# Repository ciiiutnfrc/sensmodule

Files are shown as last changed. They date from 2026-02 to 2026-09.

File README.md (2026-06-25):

# Módulo sensor de código abierto para robot móvil

El módulo de sensores consta de dos componentes principales:
1. un anillo de sensores de ultrasonido o sonar (Sonar NAvigation and Ranging) para medición de distancia
1. una unidad de medición inercial, que integra un acelerómetro y un giroscopio (IMU, Inertial Measurement Unit)

Para sujetar y distribuir los transductores de ultrasonido como anillo circular se diseñó un soporte mecánico especı́fico. Todo el conjunto se aloja en un gabinete dedicado fabricado con impresión 3D. El diseño electrónico fue realizado utilizando [KiCAD](https://www.kicad.org/), mientras que para el diseño mecánico del soporte de los transductores y el gabinete se utilizó [FreeCAD](https://www.freecad.org/); ambos decódigo abierto.

Está implementado en base a la placa de desarrollo ["Raspberry Pi Pico"](https://www.raspberrypi.com/documentation/microcontrollers/pico-series.html#pico1), cuyo firmware actúa como nodo de [ROS](https://www.ros.org/) utilizando el framework [micro-ROS](https://micro.vulcanexus.org/). Este nodo es responsable de adquirir los datos de todos los sensores y publicarlos en los topics correspondientes para su procesamiento en la computadora principal del robot.

## Videos
* [ModSens - sensores de distancia por ultrasonido](https://www.youtube.com/watch?v=mX4Z-RGdCro)
* [ModSens - visualización RViz sobre el robot RoMAA-II](https://www.youtube.com/watch?v=sf0R5RFJkfc)
* [ModSens - sensores inerciales](https://www.youtube.com/watch?v=RdyZEUkLeZU)

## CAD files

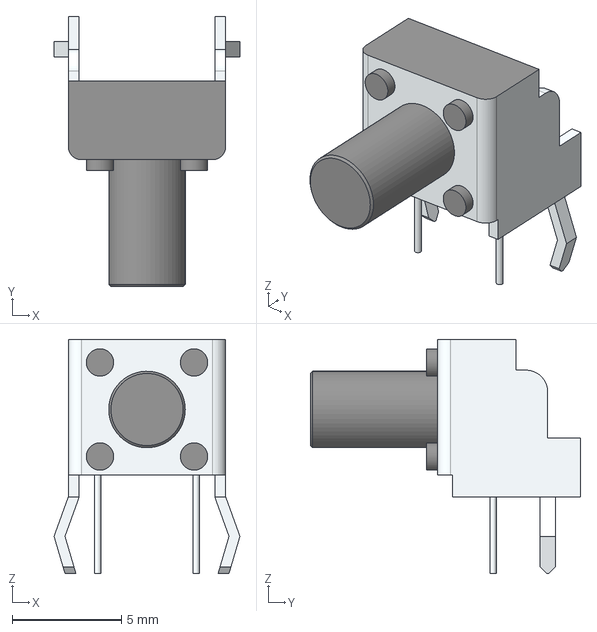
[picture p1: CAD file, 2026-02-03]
hardware/3DModels/SW-DTSA-65K-V.stp
8.50 x 12.3 x 10.7 mm

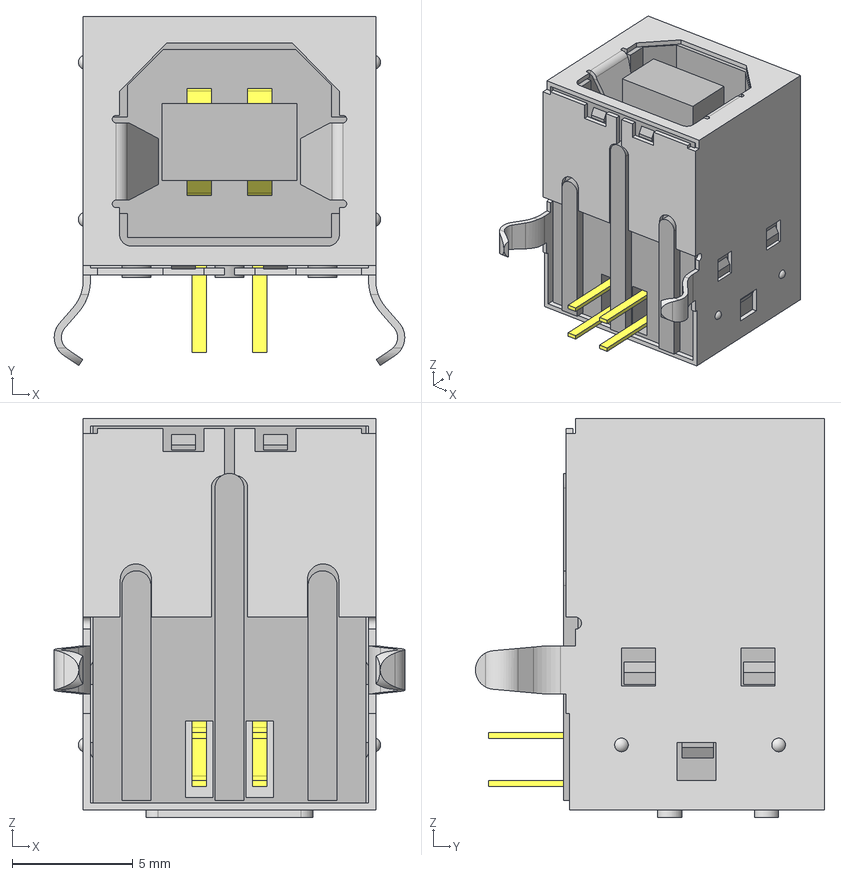
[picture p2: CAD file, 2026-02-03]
hardware/3DModels/USB-B-S-F-B-TH.stp
14.5 x 14.4 x 16.5 mm
USB-B-S-TH_S
USB-B-S-B-TH_B
USB-B-S-TH_P

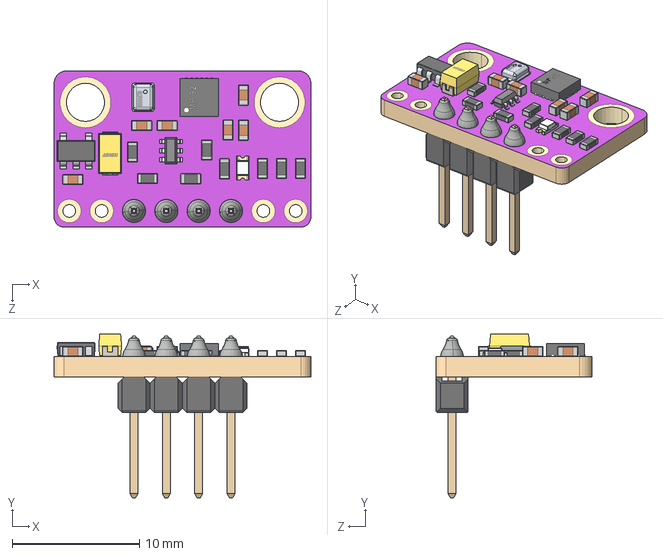
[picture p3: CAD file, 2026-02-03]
hardware/3DModels/IMU.STEP
20.2 x 12.9 x 12.3 mm

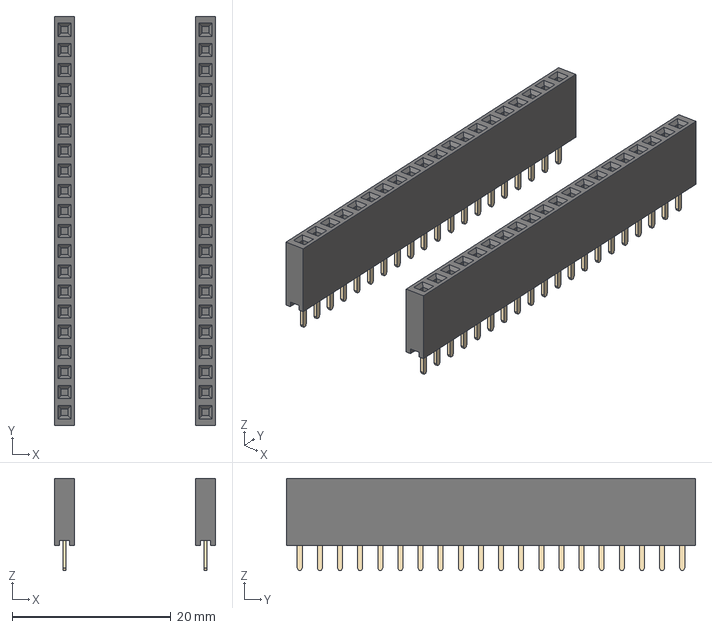
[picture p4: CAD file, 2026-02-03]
hardware/3DModels/DIP-40_W17.78mm_Socket.step
20.3 x 51.6 x 11.6 mm
SIP-20_Socket x 2

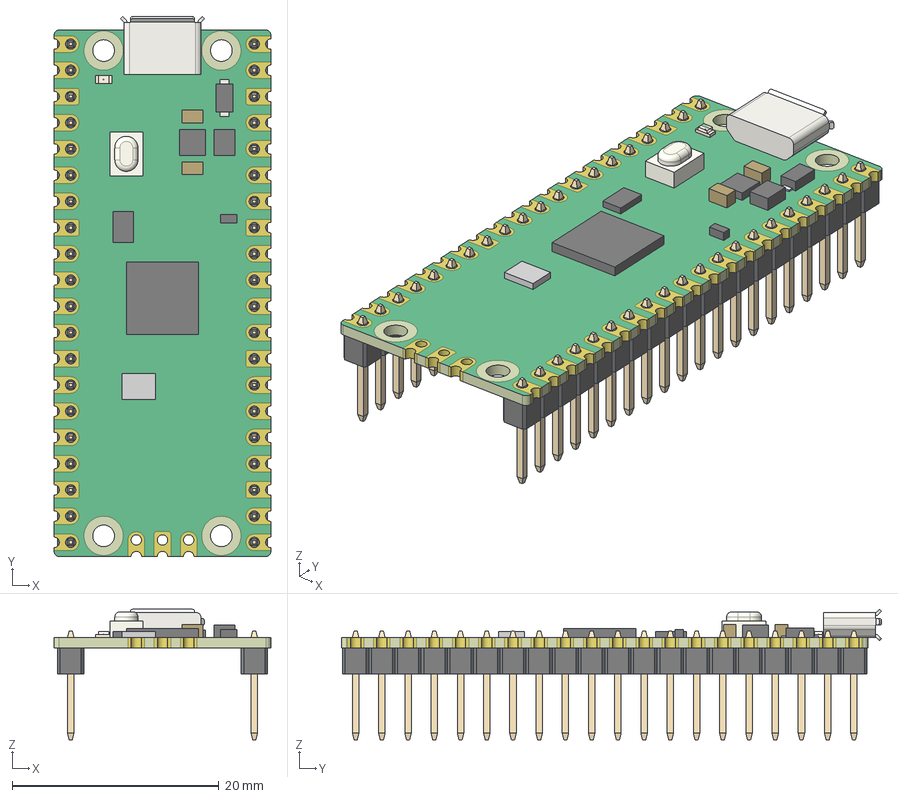
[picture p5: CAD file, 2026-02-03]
hardware/3DModels/RaspberryPi_Pico_AddedHeaders_Socketed.step
21.0 x 52.3 x 12.6 mm
Pico_Board
C1_47u
C2_47u
D1_MBR120VLSFT1G
D2_QSME-C194_Base
D2_QSME-C194_Phosphor
D2_QSME-C194_Lens
J1_690T505-x62-01x
L1_2u2
Q1_DMG1012T
SW1_TP-1221U-K9K5325
U1_RP2040
U2_RT6150B-33GQW
U3_W25Q16JVUXIQ
X1_X12M000000S096
SIP-20_Header x 2

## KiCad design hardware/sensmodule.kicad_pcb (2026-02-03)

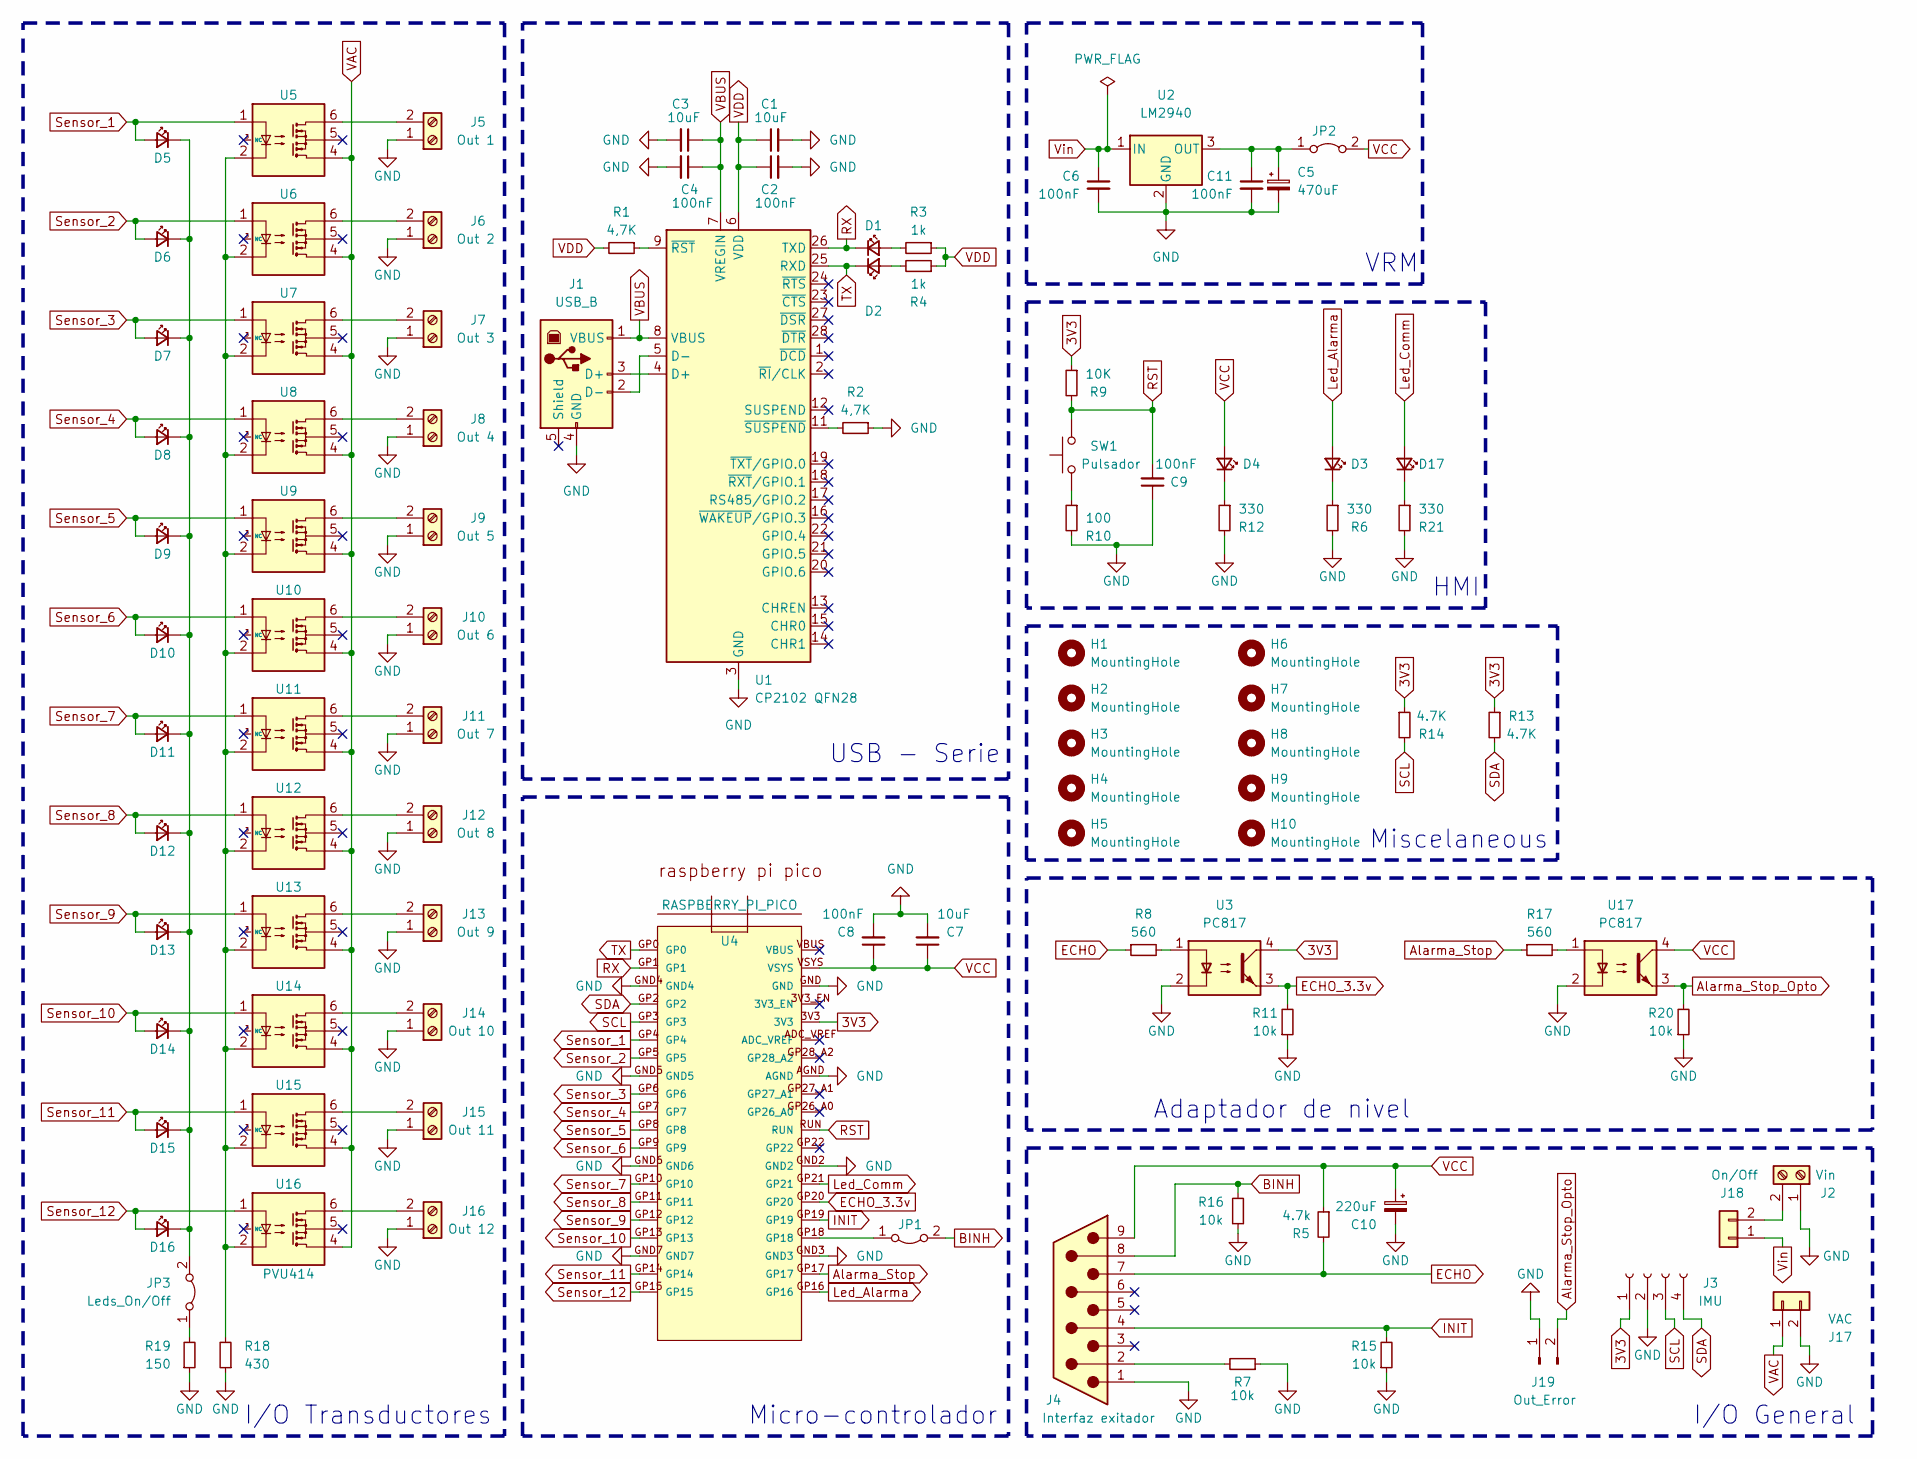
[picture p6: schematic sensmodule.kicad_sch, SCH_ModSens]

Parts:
C1, C3, C7: 10uF; C_0805_2012Metric_Pad1.18x1.45mm_HandSolder
C2, C4, C6, C8, C9, C11: 100nF; C_0805_2012Metric_Pad1.18x1.45mm_HandSolder
C5: 470uF; CP_Radial_D6.3mm_P2.50mm
C10: 220uF; CP_Radial_D5.0mm_P2.00mm
D1: TX LED Verde; LED_D3.0mm_Clear
D2: RX LED Azul; LED_D3.0mm_Clear
D3, D17: LED Verde 3mm; PinHeader_1x02_P2.54mm_Vertical
D4: LED Amarillo 3mm; PinHeader_1x02_P2.54mm_Vertical
D5, D6, D7, D8, D9, D10, D11, D12, D13, D14, D15, D16: LED Rojo 3mm; LED_D3.0mm_Clear
H1, H2, H3, H4, H5, H6, H7, H8, H9, H10: MountingHole; MountingHole_3.2mm_M3
J1: USB_B; USB_B_OST_USB-B1HSxx_Horizontal
J2: Vin; PhoenixContact_MC_1,5_2-G-5.08_1x02_P5.08mm_Horizontal
J3: IMU; PinSocket_1x04_P2.54mm_Vertical
J4: Interfaz exitador; Molex_Picoflex_90325-0010_2x05_P1.27mm_Vertical
J5: Out 1; PhoenixContact_MC_1,5_2-G-5.08_1x02_P5.08mm_Horizontal
J6: Out 2; PhoenixContact_MC_1,5_2-G-5.08_1x02_P5.08mm_Horizontal
J7: Out 3; PhoenixContact_MC_1,5_2-G-5.08_1x02_P5.08mm_Horizontal
J8: Out 4; PhoenixContact_MC_1,5_2-G-5.08_1x02_P5.08mm_Horizontal
J9: Out 5; PhoenixContact_MC_1,5_2-G-5.08_1x02_P5.08mm_Horizontal
J10: Out 6; PhoenixContact_MC_1,5_2-G-5.08_1x02_P5.08mm_Horizontal
J11: Out 7; PhoenixContact_MC_1,5_2-G-5.08_1x02_P5.08mm_Horizontal
J12: Out 8; PhoenixContact_MC_1,5_2-G-5.08_1x02_P5.08mm_Horizontal
J13: Out 9; PhoenixContact_MC_1,5_2-G-5.08_1x02_P5.08mm_Horizontal
J14: Out 10; PhoenixContact_MC_1,5_2-G-5.08_1x02_P5.08mm_Horizontal
J15: Out 11; PhoenixContact_MC_1,5_2-G-5.08_1x02_P5.08mm_Horizontal
J16: Out 12; PhoenixContact_MC_1,5_2-G-5.08_1x02_P5.08mm_Horizontal
J17: VAC; Molex_KK-254_AE-6410-02A_1x02_P2.54mm_Vertical
J18: On/Off; Molex_KK-254_AE-6410-02A_1x02_P2.54mm_Vertical
J19: Out_Error; PinHeader_1x02_P2.54mm_Vertical
JP1: BINH_On/Off; SolderJumper-2_P1.3mm_Open_Pad1.0x1.5mm
JP2: Main_On/Off; SolderJumper-2_P1.3mm_Open_Pad1.0x1.5mm
JP3: Leds_On/Off; PinHeader_1x02_P2.54mm_Vertical
R1, R2: 4,7K; R_0805_2012Metric_Pad1.20x1.40mm_HandSolder
R3, R4: 1k; R_0805_2012Metric_Pad1.20x1.40mm_HandSolder
R5: 4.7k; R_0805_2012Metric_Pad1.20x1.40mm_HandSolder
R6, R12, R21: 330; R_0805_2012Metric_Pad1.20x1.40mm_HandSolder
R7, R11, R15, R16, R20: 10k; R_0805_2012Metric_Pad1.20x1.40mm_HandSolder
R8, R17: 560; R_0805_2012Metric_Pad1.20x1.40mm_HandSolder
R9: 10K; R_0805_2012Metric_Pad1.20x1.40mm_HandSolder
R10: 100; R_0805_2012Metric_Pad1.20x1.40mm_HandSolder
R13, R14: 4.7K; R_0805_2012Metric_Pad1.20x1.40mm_HandSolder
R18: 430; R_0805_2012Metric_Pad1.20x1.40mm_HandSolder
R19: 150; R_0805_2012Metric_Pad1.20x1.40mm_HandSolder
SW1: Pulsador; SW_SPST_Omron_B3F-315x_Angled
U1: CP2102 QFN28; QFN-28-1EP_5x5mm_P0.5mm_EP3.35x3.35mm
U2: LM2940; TO-220-3_Horizontal_TabDown
U3, U17: PC817; DIP-4_W7.62mm_Socket_LongPads
U4: RASPBERRY_PI_PICO
U5, U6, U7, U8, U9, U10, U11, U12, U13, U14, U15, U16: PVU414; DIP-6_W7.62mm_Socket_LongPads

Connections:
3V3: J3.1, R9.1, R13.1, R14.1, U3.4, U4.3V3
Alarma_Stop: R17.1, U4.GP17
Alarma_Stop_Opto: J19.2, R20.2, U17.3
BINH: J4.8, JP1.2 (B), R16.2
ECHO: J4.7, R5.2, R8.1
ECHO_3.3v: R11.2, U3.3, U4.GP20
GND: C1.2, C2.2, C3.2, C4.2, C5.2, C6.2, C7.2, C8.2, C9.1, C10.2, C11.2, J1.4 (GND), J2.1, J3.2, J4.1, J5.1, J6.1, J7.1, J8.1, J9.1, J10.1, J11.1, J12.1, J13.1, J14.1, J15.1, J16.1, J17.2, J19.1, R2.1, R6.2, R7.1, R10.2, R11.1, R12.2, R15.1, R16.1, R18.1, R19.1, R20.1, R21.2, U1.3 (GND), U1.29 (GND), U2.2 (GND), U3.2, U4.AGND, U4.GND, U4.GND2, U4.GND3, U4.GND4, U4.GND5, U4.GND6, U4.GND7, U17.2
INIT: J4.4, R15.2, U4.GP19
Led_Alarma: D3.2 (A), U4.GP16
Led_Comm: D17.2 (A), U4.GP21
unnamed: D1.2 (A), R3.2
unnamed: D2.2 (A), R4.2
unnamed: D3.1 (K), R6.1
unnamed: D4.1 (K), R12.1
unnamed: D5.1 (K), D6.1 (K), D7.1 (K), D8.1 (K), D9.1 (K), D10.1 (K), D11.1 (K), D12.1 (K), D13.1 (K), D14.1 (K), D15.1 (K), D16.1 (K), JP3.2 (B)
unnamed: D17.1 (K), R21.1
unnamed: J1.3 (D+), U1.4 (D+)
unnamed: J1.2 (D-), U1.5 (D-)
unnamed: J4.2, R7.2
unnamed: J5.2, U5.6
unnamed: J6.2, U6.6
unnamed: J7.2, U7.6
unnamed: J8.2, U8.6
unnamed: J9.2, U9.6
unnamed: J10.2, U10.6
unnamed: J11.2, U11.6
unnamed: J12.2, U12.6
unnamed: J13.2, U13.6
unnamed: J14.2, U14.6
unnamed: J15.2, U15.6
unnamed: J16.2, U16.6
unnamed: J2.2, J18.2
unnamed: JP1.1 (A), U4.GP18
unnamed: C5.1, C11.1, JP2.1 (A), U2.3 (OUT)
unnamed: JP3.1 (A), R19.2
unnamed: R8.2, U3.1
unnamed: R10.1, SW1.1
unnamed: R17.2, U17.1
unnamed: R18.2, U5.2, U6.2, U7.2, U8.2, U9.2, U10.2, U11.2, U12.2, U13.2, U14.2, U15.2, U16.2
unnamed: R1.1, U1.9 (~RST)
unnamed: R2.2, U1.11 (~SUSPEND)
RST: C9.2, R9.2, SW1.2, U4.RUN
RX: D1.1 (K), U1.26 (TXD), U4.GP1
SCL: J3.3, R14.2, U4.GP3
SDA: J3.4, R13.2, U4.GP2
Sensor_1: D5.2 (A), U4.GP4, U5.1
Sensor_2: D6.2 (A), U4.GP5, U6.1
Sensor_3: D7.2 (A), U4.GP6, U7.1
Sensor_4: D8.2 (A), U4.GP7, U8.1
Sensor_5: D9.2 (A), U4.GP8, U9.1
Sensor_6: D10.2 (A), U4.GP9, U10.1
Sensor_7: D11.2 (A), U4.GP10, U11.1
Sensor_8: D12.2 (A), U4.GP11, U12.1
Sensor_9: D13.2 (A), U4.GP12, U13.1
Sensor_10: D14.2 (A), U4.GP13, U14.1
Sensor_11: D15.2 (A), U4.GP14, U15.1
Sensor_12: D16.2 (A), U4.GP15, U16.1
TX: D2.1 (K), U1.25 (RXD), U4.GP0
VAC: J17.1, U5.4, U6.4, U7.4, U8.4, U9.4, U10.4, U11.4, U12.4, U13.4, U14.4, U15.4, U16.4
VBUS: C3.1, C4.1, J1.1 (VBUS), U1.7 (VREGIN), U1.8 (VBUS)
VCC: C7.1, C8.1, C10.1, D4.2 (A), J4.9, JP2.2 (B), R5.1, U4.VSYS, U17.4
VDD: C1.1, C2.1, R1.2, R3.1, R4.1, U1.6 (VDD)
Vin: C6.1, J18.1, U2.1 (IN)

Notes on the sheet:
Adaptador de nivel
VRM
Micro-controlador
I/O General
Miscelaneous
I/O Transductores
USB - Serie
HMI

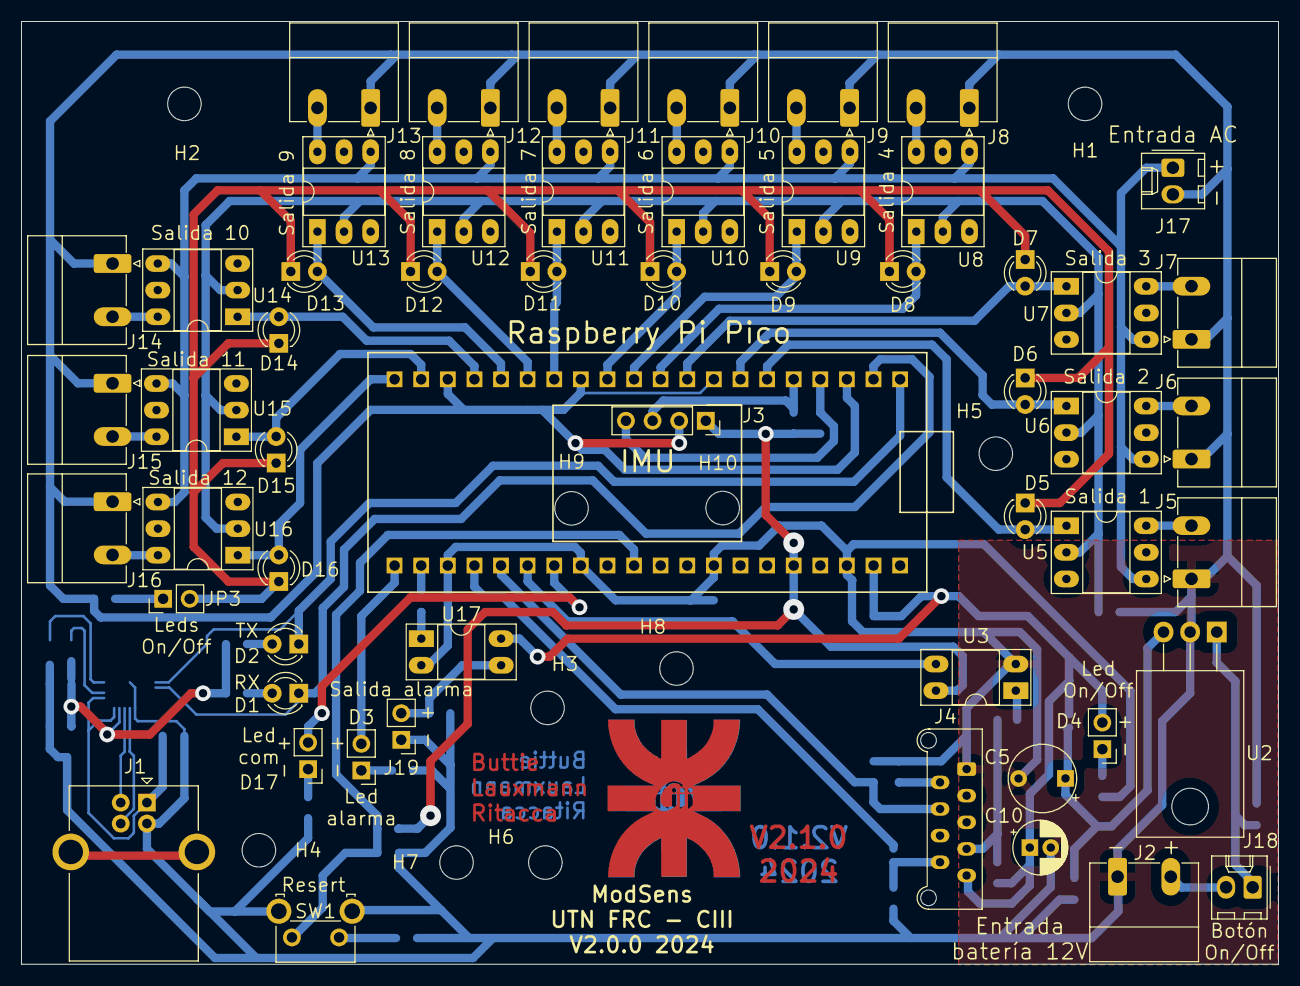
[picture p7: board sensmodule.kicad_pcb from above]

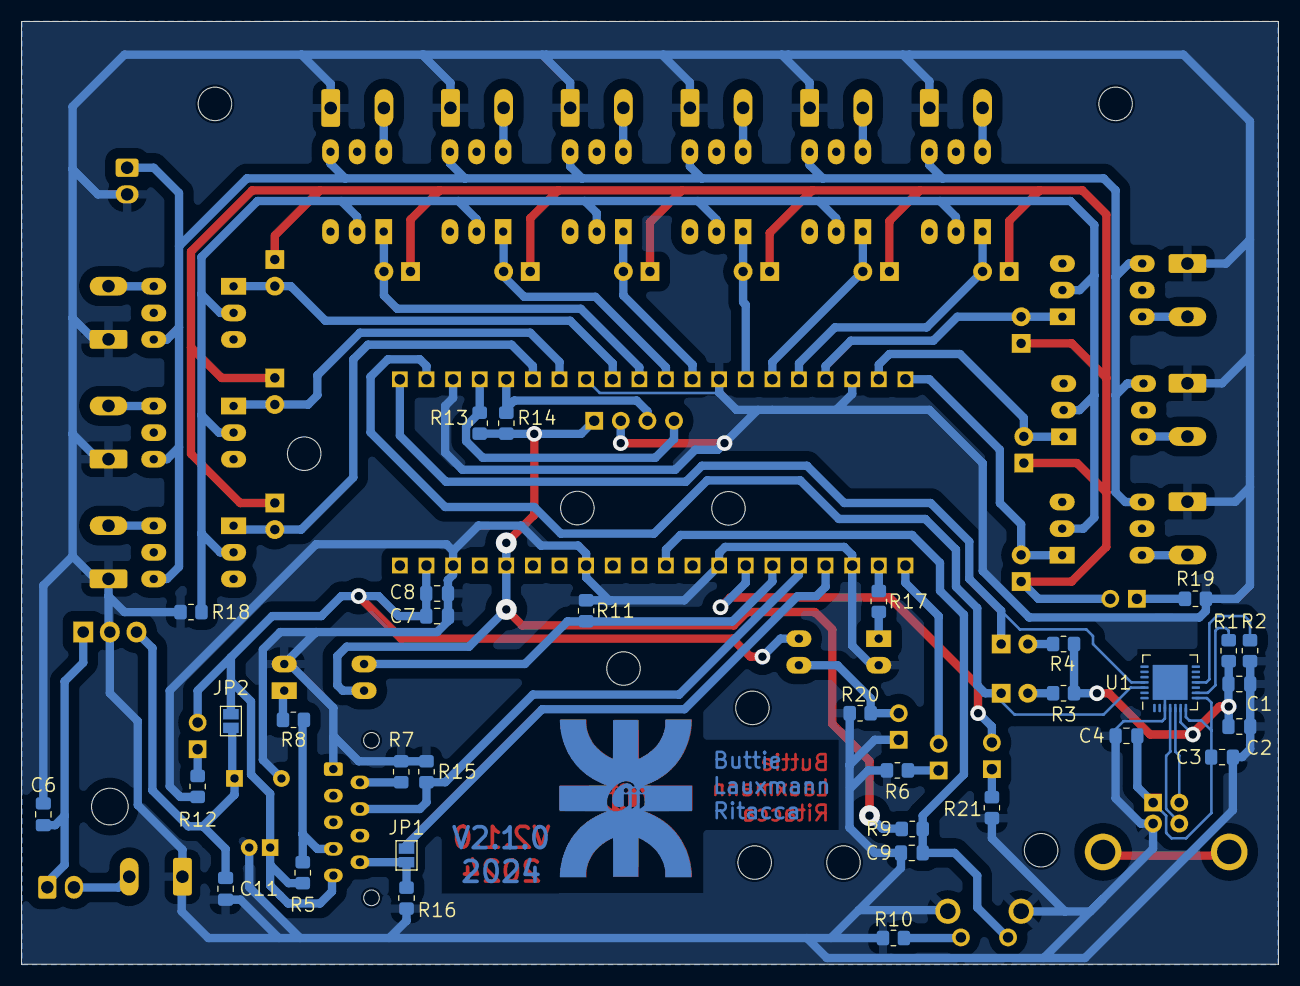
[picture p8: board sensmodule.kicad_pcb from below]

Board: 2 copper layers, 120.0 x 90.0 mm, 99 parts (33 on the bottom side), 63 nets.

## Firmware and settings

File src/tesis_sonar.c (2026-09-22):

/////////////////////////////////////////////////////
//LIBRERIAS

//Librerias STD
#include <stdio.h>
#include <unistd.h>
#include <math.h>

//Librerias propias de MicroRos
#include <rcl/rcl.h>
#include <rcl/error_handling.h>
#include <rclc/rclc.h>
#include <rclc/executor.h>
#include <std_msgs/msg/int16.h>
#include <std_msgs/msg/float32.h>
#include <rmw_microros/rmw_microros.h>
#include <micro_ros_utilities/type_utilities.h>

//Librerias propias de raspi pico
#include "pico/stdlib.h"
#include "pico_uart_transports.h"
#include "hardware/gpio.h"
#include "hardware/timer.h"

//I2C Para IMU
#include "hardware/i2c.h"
#include "pico/binary_info.h"

//Librerias de mensajes
#include <sensor_msgs/msg/range.h>
#include <sensor_msgs/msg/imu.h>

/////////////////////////////////////////////////////
//CONSTANTES

//Tiempo de INIT
#define TON_INIT 55
#define TOFF_INIT 20

//Numero de sensores por defecto
#define MAX_SENSORES 9

//Distancia maxima y minima por defecto (Mts)
#define MAX_DIST 5 
#define MIN_DIST 0.4 

#define HISTERESIS 0.05 //En mts

#define UMBRAL_SEGURIDAD 0.5

//Lobulo del sensor
#define FIELD_VIEW 0.244346

//Frecuencias de Publicacion (Hz)
#define FREC_SONAR 1
#define FREC_IMU 10

#define FREC_CALLBACK 20

#define MAX_FREC_SONAR 2
#define MAX_FREC_IMU 20

#define MIN_FREC_SONAR 0.5
#define MIN_FREC_IMU 5

//GPIO
#define LED_PIN 21
#define LED_INTEGRADO 25
#define ECHO 20 
#define INIT 19 

#define SEG_1 16
#define SEG_2 17

//UART
#define UART_TX_PIN 0
#define UART_RX_PIN 1
#define UART_USADA uart0
#define BAUD_RATE 921600

//ROS
#define NODE_NAME "mod_sens"
#define NAMESPACE_NAME "modsens"
#define TOPIC_NAME_SONAR "range"
#define TOPIC_NAME_IMU "imu"
#define TOPIC_NAME_CANT_SENSORES "cant_sensores"
#define TOPIC_NAME_DIST_SEG "dist_seguridad"

#define TIMEOUT_MS 1000
#define INTENTOS_CONN 10

//I2C
#define I2C_PORT i2c1
#define SDA_PIN 2
#define SCL_PIN 3
#define FREQ_I2C 100 * 1000

#define LSM6DS3_ADDR 0x6B
#define LSM6DS3_WHO_AM_I  0x0F
#define LSM6DS3_CTRL1_XL  0x10
#define LSM6DS3_CTRL2_G   0x11
#define LSM6DS3_OUTX_L_XL 0x28
#define OUTX_L_G 0x22

#define PIN_OCTO_1 4
#define PIN_OCTO_2 5
#define PIN_OCTO_3 6
#define PIN_OCTO_4 7
#define PIN_OCTO_5 8
#define PIN_OCTO_6 9
#define PIN_OCTO_7 10
#define PIN_OCTO_8 11
#define PIN_OCTO_9 12
#define PIN_OCTO_10 13
#define PIN_OCTO_11 14
#define PIN_OCTO_12 15

/////////////////////////////////////////////////////
//VARIABLES GLOBALES

//Timer
uint64_t start_time = 0, end_time = 0;
double elapsed_time_us = 0;

uint64_t periodo_imu = 0;
uint64_t periodo_sonar = 0;

//Medicion
double medicion = 0;
double CORRECCION_IMU_ACEL = (double)100/(double)170408;
double CORRECCION_IMU_GIRO = (double)4.375/(double)1000 * (double)0.0175;
int16_t accel_data[3];
int16_t giro_data[3];

//Variables nodo
rcl_node_t node;

rcl_publisher_t publisher_sonar;
rcl_publisher_t publisher_imu;

rcl_subscription_t subscriber_cant_sonar;
rcl_subscription_t subscriber_seguridad;

sensor_msgs__msg__Range__Sequence* sonar_msg;
sensor_msgs__msg__Imu imu_msg;

rcl_timer_t timer_publ_sonar;
rcl_timer_t timer_publ_imu;
int64_t periodo;

rclc_support_t support;

rcl_allocator_t allocator;

// Message object to receive publisher data
std_msgs__msg__Int16 msg_sensores;
std_msgs__msg__Float32 msg_seg;

//Multiplexado
int n_sensor_leido = 0;
int lugar_sensor_leido = 0;

bool medicion_nueva = 0;

//Definiciones
bool sensores_activar[12] = {1,1,1,1,1,1,1,1,1,0,0,0};
int cant_sensores = 0;
int frec_imu = FREC_IMU;
int new_frec_imu = FREC_IMU;
int frec_sonar = FREC_SONAR;

//Cuenta para publicacion
int contador_imu = 0;
int contador_sonar = 0;
int contador_frec = 0;

//Sensado distancia minima
double umbral_seguridad = UMBRAL_SEGURIDAD;
int sensor_seguridad = 0;

/////////////////////////////////////////////////////
//FUNCIONES

/*! \brief Inicializar todos los pines de GPIO
 */
void init_pins(){

    //Seteo de pines
    gpio_init(LED_PIN);
    gpio_set_dir(LED_PIN, GPIO_OUT);

    gpio_init(LED_INTEGRADO);
    gpio_set_dir(LED_INTEGRADO, GPIO_OUT);

    gpio_init(ECHO);
    gpio_set_dir(ECHO, GPIO_IN);

    gpio_init(INIT);
    gpio_set_dir(INIT, GPIO_OUT);

    gpio_init(PIN_OCTO_12);
    gpio_set_dir(PIN_OCTO_12, GPIO_OUT);
    gpio_init(PIN_OCTO_11);
    gpio_set_dir(PIN_OCTO_11, GPIO_OUT);
    gpio_init(PIN_OCTO_10);
    gpio_set_dir(PIN_OCTO_10, GPIO_OUT);
    gpio_init(PIN_OCTO_9);
    gpio_set_dir(PIN_OCTO_9, GPIO_OUT);
    gpio_init(PIN_OCTO_8);
    gpio_set_dir(PIN_OCTO_8, GPIO_OUT);
    gpio_init(PIN_OCTO_7);
    gpio_set_dir(PIN_OCTO_7, GPIO_OUT);
    gpio_init(PIN_OCTO_6);
    gpio_set_dir(PIN_OCTO_6, GPIO_OUT);
    gpio_init(PIN_OCTO_5);
    gpio_set_dir(PIN_OCTO_5, GPIO_OUT);
    gpio_init(PIN_OCTO_4);
    gpio_set_dir(PIN_OCTO_4, GPIO_OUT);
    gpio_init(PIN_OCTO_3);
    gpio_set_dir(PIN_OCTO_3, GPIO_OUT);
    gpio_init(PIN_OCTO_2);
    gpio_set_dir(PIN_OCTO_2, GPIO_OUT);
    gpio_init(PIN_OCTO_1);
    gpio_set_dir(PIN_OCTO_1, GPIO_OUT);

    gpio_init(SEG_1);
    gpio_set_dir(SEG_1, GPIO_OUT);
    gpio_init(SEG_2);
    gpio_set_dir(SEG_2, GPIO_OUT);
}

/*! \brief setear UART para la comunicacion serial de ROS
 */
void init_uart(){

    rmw_uros_set_custom_transport(
        true,
        NULL,
        pico_serial_transport_open,
        pico_serial_transport_close,
        pico_serial_transport_write,
        pico_serial_transport_read
    );

    //uart_init(UART_USADA, BAUD_RATE);
    //gpio_set_function(UART_TX_PIN, GPIO_FUNC_UART);    
    //gpio_set_function(UART_RX_PIN, GPIO_FUNC_UART);
}

/*! \brief Inicializar I2C para la comunicacion con la IMU
 */
void init_i2c(){

    //INICIALIZAR I2C 
    i2c_init(I2C_PORT, FREQ_I2C);

    //Setear pines SDA SCL
    gpio_set_function(SDA_PIN, GPIO_FUNC_I2C);
    gpio_set_function(SCL_PIN, GPIO_FUNC_I2C);

}


/*! \brief Inicializar arreglo de msg de sonar (sensor_msgs__msg__Range)
 */
void init_sonar(){

    sonar_msg = sensor_msgs__msg__Range__Sequence__create(MAX_SENSORES);
    sensor_msgs__msg__Range__Sequence__init(sonar_msg,MAX_SENSORES);

    //Definir que cantidad de sensores estaran activos en un principio
    int nueva_cantidad;

    for(int i = 0; i < MAX_SENSORES; i++){

        if(sensores_activar[i]){

            nueva_cantidad = nueva_cantidad+1;

        }
        
    }

    cant_sensores = nueva_cantidad;

    char frame_id[20];
    for (int i = 1; i <= MAX_SENSORES; i++) {

        // Construir el nombre del sensor con el número correspondiente
        snprintf(frame_id, sizeof(frame_id), "sensor_%d", i);

        // Asignar el nombre construido a la estructura
        strcpy(sonar_msg->data[i-1].header.frame_id.data, frame_id);
        sonar_msg->data[i-1].header.frame_id.size = strlen(sonar_msg->data[i-1].header.frame_id.data);

        sonar_msg->data[i-1].field_of_view = FIELD_VIEW;

        sonar_msg->data[i-1].radiation_type = 0;

        sonar_msg->data[i-1].max_range = MAX_DIST;

        sonar_msg->data[i-1].min_range = MIN_DIST;

    }

}


/*! \brief Inicializar mensaje IMU (sensor_msgs__msg__Imu)
 */
void init_imu(){

    memset(&imu_msg, 0, sizeof(sensor_msgs__msg__Imu));
    sensor_msgs__msg__Imu__init(&imu_msg);

    strcpy(imu_msg.header.frame_id.data, "IMU LSM6DS3");

}


/*! \brief Funcion llamada al reasignar cantidad de sensores
 * 
 * \param msgin mensaje entrante
 */
void subscription_callback_sensores(const void * msgin)
{

    // Cast received message to used type
    const std_msgs__msg__Int16 * msg_sonar = (const std_msgs__msg__Int16 *)msgin;

    // Variable to hold the processed value
    uint16_t recibido = (uint16_t) msg_sonar->data;  // Cast and get value directly
    int nueva_cantidad = 0;

    // Crear el arreglo bool (suponiendo que sensores_activar ya está definido en otro lugar)
    for (int i = 0; i < MAX_SENSORES; i++) {

        // Extraer el bit correspondiente y almacenar en el arreglo
        sensores_activar[i] = (recibido & (1 << i)) != 0;

    }

    for(int i = 0; i < MAX_SENSORES; i++){

        if(sensores_activar[i]){

            nueva_cantidad++;

        }
        
    }

    cant_sensores = nueva_cantidad;
    
    n_sensor_leido = 0;
    lugar_sensor_leido = 0;

    actualizar_periodo_sonar();

    gpio_put(SEG_1,0);
    gpio_put(SEG_2,0);

}


/*! \brief Funcion llamada para reasignar el periodo del sonar al cambiar la cantidad de sensores activos
 */
void actualizar_periodo_sonar(){

    //VER QUE CANTIDAD DE SENSORES ACTIVAR
    int nueva_cantidad;

    for(int i = 0; i < MAX_SENSORES; i++){

        if(sensores_activar[i]){

            nueva_cantidad = nueva_cantidad+1;

        }
        
    }

    cant_sensores = nueva_cantidad;

    rcl_timer_exchange_period(&timer_publ_sonar, RCL_S_TO_NS((double)1/(frec_sonar*cant_sensores)),&periodo_sonar);

}


/*! \brief Funcion llamada al reasignar la distancia de seguridad
 * 
 * \param msgin mensaje entrante
 */
void subscription_callback_seguridad(const void * msgin)
{

    float nueva_dist = 0;

    // Cast received message to used type
    const std_msgs__msg__Float32 * msg_imu = (const std_msgs__msg__Float32 *)msgin;

    // Variable to hold the processed value
    nueva_dist = (int) msg_imu->data;  // Cast and get value directly

    nueva_dist = nueva_dist;

    if(nueva_dist <= MAX_DIST && nueva_dist >= MIN_DIST){

        umbral_seguridad = nueva_dist;

        gpio_put(SEG_1,0);
        gpio_put(SEG_2,0);

    }

}

/*! \brief Leer y guardar la medicion de la IMU
 * 
 * \param accel_data datos del acelerometro
 * \param giro_data datos del giroscopio
 */
void LSM6DS3_Read_Save(int16_t *accel_data, int16_t *giro_data)
{
    uint8_t data[6];
    uint8_t reg;

    // Read accelerometer data
    reg = LSM6DS3_OUTX_L_XL;  
    i2c_write_blocking(I2C_PORT, LSM6DS3_ADDR, &reg, 1, true);
    i2c_read_blocking(I2C_PORT, LSM6DS3_ADDR, data, 6, false);

    accel_data[0] = (int16_t)(data[1] << 8 | data[0]);  // X-axis
    accel_data[1] = (int16_t)(data[3] << 8 | data[2]);  // Y-axis
    accel_data[2] = (int16_t)(data[5] << 8 | data[4]);  // Z-axis

    // Scale the accelerometer data
    imu_msg.linear_acceleration.x = accel_data[0] * CORRECCION_IMU_ACEL;
    imu_msg.linear_acceleration.y = accel_data[1] * CORRECCION_IMU_ACEL;
    imu_msg.linear_acceleration.z = accel_data[2] * CORRECCION_IMU_ACEL;

    // Read gyroscope data
    reg = OUTX_L_G;  // Changed to the correct gyroscope data register
    i2c_write_blocking(I2C_PORT, LSM6DS3_ADDR, &reg, 1, true);
    i2c_read_blocking(I2C_PORT, LSM6DS3_ADDR, data, 6, false);

    giro_data[0] = (int16_t)(data[1] << 8 | data[0]);  // X-axis
    giro_data[1] = (int16_t)(data[3] << 8 | data[2]);  // Y-axis
    giro_data[2] = (int16_t)(data[5] << 8 | data[4]);  // Z-axis

    imu_msg.angular_velocity.x = giro_data[0] * CORRECCION_IMU_GIRO;
    imu_msg.angular_velocity.y = giro_data[1] * CORRECCION_IMU_GIRO;
    imu_msg.angular_velocity.z = giro_data[2] * CORRECCION_IMU_GIRO;

    // Timestamp for the message
    imu_msg.header.stamp.nanosec = time_us_64() % 1000000;
    imu_msg.header.stamp.sec = time_us_64() / 1000000;
}

/*! \brief Funcion de error. 
 * 
 * \brief Se entra en un bucle infinito mientras el LED de error parpadea.
 * 
 * \param error Codigo de error a mostrar
 */
void error_func(int error)
{
    while (1) {

        for(int i = 0; i < error; i++){

            gpio_put(LED_PIN, 1);
            sleep_ms(500);  
            gpio_put(LED_PIN, 0);
            sleep_ms(500); 

        }

        gpio_put(LED_PIN, 0);
        sleep_ms(3000);  
    
    }
}

void publicar_imu(rcl_timer_t *timer, int64_t last_call_time){

    LSM6DS3_Read_Save(accel_data, giro_data); // Actualiza los datos del IMU

    rcl_publish(&publisher_imu, &imu_msg, NULL);

}


/*! \brief Funcion llamada por interrupcion de timer que envia mensaje de ROS
 * 
 * \param timer timer asociado
 * \param last_call_time tiempo de ultimo llamado
 */
void publicar_sonar(rcl_timer_t *timer, int64_t last_call_time)
{

    //Timeout para el caso que se desconecte un sensor
    if(medicion_nueva == 0){

        sonar_msg->data[lugar_sensor_leido].header.stamp.nanosec=0;
        sonar_msg->data[lugar_sensor_leido].header.stamp.sec=0;
        sonar_msg->data[lugar_sensor_leido].range=MAX_DIST;

    }

    rcl_ret_t ret = rcl_publish(&publisher_sonar, &sonar_msg->data[lugar_sensor_leido], NULL);

    //sonar_publicado ++;
    lugar_sensor_leido ++;

    cambiar_sensor();

    medicion_nueva = 0;

}
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
int main(){

    /////////////////////////////////////////////////////
    //INICIALIZACION GPIO / UART / I2C / LSM6DS3

    stdio_init_all();

    init_pins();

    /////////////////////
    //LED DE SET UP (SE APAGA AL TERMINAR INICIALIZACION)
    gpio_put(LED_PIN, 1);
    /////////////////////

    init_uart();

    init_i2c();

    sleep_ms(500);

    LSM6DS3_Init();

    /////////////////////////////////////////////////////
    //CONFIGURACION ROS

    allocator = rcl_get_default_allocator();

    // Inicializar support object
    rcl_ret_t rc = rclc_support_init(&support, 0, NULL, &allocator);

    //Esperar a conexion con maquina a bordo
    rcl_ret_t ret = rmw_uros_ping_agent(TIMEOUT_MS, INTENTOS_CONN);
    if (ret != RCL_RET_OK) {
        error_func(1);
    }

    // Inicializar nodo
    const char * node_name = NODE_NAME;

    const char * namespace = NAMESPACE_NAME;

    rc = rclc_node_init_default(&node, node_name, namespace, &support);
    if (rc != RCL_RET_OK) {
        error_func(2);    
    }

    // Init topico range
    rc = rclc_publisher_init_default(
        &publisher_sonar,
        &node,
        ROSIDL_GET_MSG_TYPE_SUPPORT(sensor_msgs, msg, Range),
        TOPIC_NAME_SONAR);
    if (rc != RCL_RET_OK) {
        error_func(3);    
    }

    // Init topico imu
    rc = rclc_publisher_init_default(
        &publisher_imu,
        &node,
        ROSIDL_GET_MSG_TYPE_SUPPORT(sensor_msgs, msg, Imu),
        TOPIC_NAME_IMU);
    if (rc != RCL_RET_OK) {
        error_func(4);    
    }

    // Init suscriptor CANT SONAR
    rc = rclc_subscription_init_default(
        &subscriber_cant_sonar, 
        &node,
        ROSIDL_GET_MSG_TYPE_SUPPORT(std_msgs, msg, Int16), 
        TOPIC_NAME_CANT_SENSORES);
    if (RCL_RET_OK != rc) {
        error_func(5);
    } 

    // Init suscriptor SEGURIDAD
    rc = rclc_subscription_init_default(
        &subscriber_seguridad, 
        &node,
        ROSIDL_GET_MSG_TYPE_SUPPORT(std_msgs, msg, Float32), 
        TOPIC_NAME_DIST_SEG);
    if (RCL_RET_OK != rc) {
        error_func(6);
    } 

    //////////////////////////////////////////////////////
    //INICIALIZACION DATOS MENSAJES

    //Inicializacion array sonar
    init_sonar();

    //Inicializacion imu
    init_imu();

    //Inicializacion suscribers

    memset(&msg_sensores, 0, sizeof(std_msgs__msg__Int16));
    std_msgs__msg__Int16__init(&msg_sensores);

    memset(&msg_seg, 0, sizeof(std_msgs__msg__Float32));
    std_msgs__msg__Float32__init(&msg_seg);

    rclc_executor_t executor_pub_sonar;
    rclc_executor_init(&executor_pub_sonar, &support.context, 1, &allocator);

    rclc_executor_t executor_pub_imu;
    rclc_executor_init(&executor_pub_imu, &support.context, 1, &allocator);

    rclc_executor_t executor_sub_cant;
    rclc_executor_init(&executor_sub_cant, &support.context, 1, &allocator); 

    rclc_executor_t executor_sub_seg;
    rclc_executor_init(&executor_sub_seg, &support.context, 1, &allocator);

    //////////////////////////////////////////////////////
    //INTERRUPCIONES ROS

    periodo_imu = RCL_S_TO_NS((double)1/FREC_IMU);
    periodo_sonar =  RCL_S_TO_NS((double)1/FREC_IMU);

    //Interrupcion por timer para publicacion
    rclc_timer_init_default(&timer_publ_sonar,&support,periodo_sonar,&publicar_sonar);

    rclc_timer_init_default(&timer_publ_imu,&support,periodo_imu,&publicar_imu);

    rclc_executor_add_subscription(&executor_sub_cant, &subscriber_cant_sonar, &msg_sensores, &subscription_callback_sensores, ON_NEW_DATA);

    rclc_executor_add_subscription(&executor_sub_seg, &subscriber_seguridad, &msg_seg, &subscription_callback_seguridad, ON_NEW_DATA);

    //////////////////////////////////////////////////////

    //Vincular timer
    rclc_executor_add_timer(&executor_pub_sonar, &timer_publ_sonar);

    rclc_executor_add_timer(&executor_pub_imu, &timer_publ_imu);

    //////////////////////////////////////////////////////
    //INTERRUPCION ECHO SONAR

    //Interrupcion gpio ECHO
    gpio_set_irq_enabled_with_callback(ECHO, GPIO_IRQ_EDGE_RISE, true, &callback_echo);

    actualizar_periodo_sonar();

    /////////////////////
    //FINALIZACION SET UP
    gpio_put(LED_PIN, 0);
    /////////////////////

    /////////////////////////////////////////////////////
    //EJECUCION INFINITA

    while(1){
        
        //Chequear por datos nuevos
        rclc_executor_spin_some(&executor_pub_sonar, RCL_MS_TO_NS(10));
        rclc_executor_spin_some(&executor_pub_imu, RCL_MS_TO_NS(10));
        rclc_executor_spin_some(&executor_sub_cant, RCL_MS_TO_NS(10));
        rclc_executor_spin_some(&executor_sub_seg, RCL_MS_TO_NS(10));


        //Si la ultima medicion ya se envio, iniciar una medicion nueva.
        if(medicion_nueva == 0){

            //INICIAR NUEVA MEDICION
            start_time = time_us_64();
            gpio_put(INIT, 1);
            sleep_ms(TON_INIT);  
            gpio_put(INIT, 0);
            sleep_ms(TOFF_INIT);

        }

    }
    return 0;
}

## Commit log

2026-01-29 Add KiCAD files of the sensor module board
    [sensmodule.kicad_pcb, sensmodule.kicad_sch]
2026-02-03 Add missing 3D models :pencil:
    [DIP-40_W17.78mm_Socket.step, IMU.STEP, RaspberryPi_Pico_AddedHeaders_Socketed.step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]
2026-09-22 Fix ROS message type error
    [tesis_sonar.c]
2026-09-22 Fix bug of UART baud rate
    [tesis_sonar.c]

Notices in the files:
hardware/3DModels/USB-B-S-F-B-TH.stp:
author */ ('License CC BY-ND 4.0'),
